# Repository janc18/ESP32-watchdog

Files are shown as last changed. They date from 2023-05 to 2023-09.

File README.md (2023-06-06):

# ESP32-watchdog 

This watch will be a multipurpose watch, that will have some kind of Espressif's MCU because it's cheap a come with good features like
Bluetooth and Wi-Fi.

I want to have the more compact design, with that said, the screen and battery define the size watch. 

Searching on Aliexpress I found the next options 

|ID|Technology type|Consumption (mAh) - Voltage (V)|Communication interface|Size|Price|Resolution|
|-|-|-|-|-|-|-|
|1|TFT-LCD|95mAh-5v|UART|47,5mm diameter x 27,0mm de height|371 MX|240px|
|2|Electronic paper screen Monochrome|0.15mAh|-|1.28in|574.29 MX 2 units| 128px|

**I decided to use the next LCD screen**

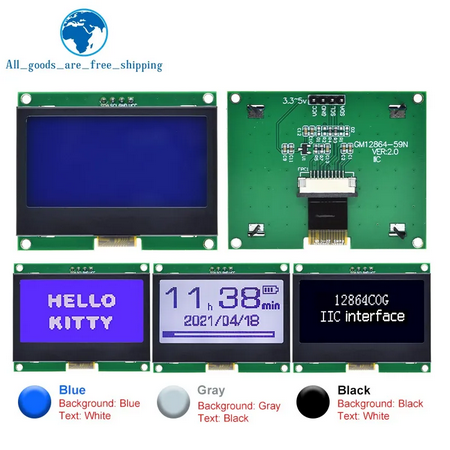
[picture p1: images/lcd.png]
lcd_screen


[Here is the purchase link](https://es.aliexpress.com/item/1005004617618178.html)

**Maybe in the next iteration I will choose for a smaller screen**

## Links
1. https://es.aliexpress.com/item/1005005295747021.html
2. https://es.aliexpress.com/item/1005004555311346.html

## Buttons 
For applications control it is needed to have some kind of inputs, like in common watches,with the hour configured through buttons.
One option is to have capacitive buttons or micro-buttons.

## Capacitive touch sensor
Following this document https://ww1.microchip.com/downloads/en/AppNotes/Capacitive-Touch-Sensor-Design-Guide-DS00002934-B.pdf
This type of sensor touch it seems the best option, it is called "slide sensor", at "Extend Interpolation" form.

## Programming port 
The programming port it will be a micro-usb with the CHG340

## ESP32-S3's power consumption 

|Mode|Power consumption|
|-|-|
|Recommended|500(mA)|
|deep sleep|7-8(uA)|
|light sleep|240(uA)|
|wifi|355mA|

In the case that I want to use Wi-Fi with another application running for three hours on a day and with powered on screen.

## Conceptual design

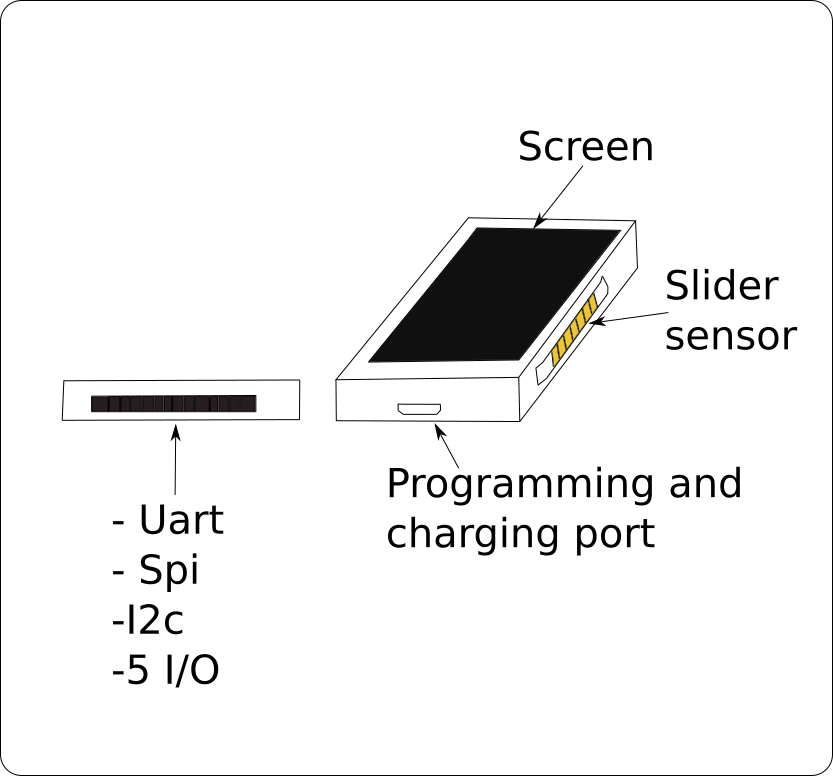
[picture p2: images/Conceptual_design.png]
design


## First PCB design

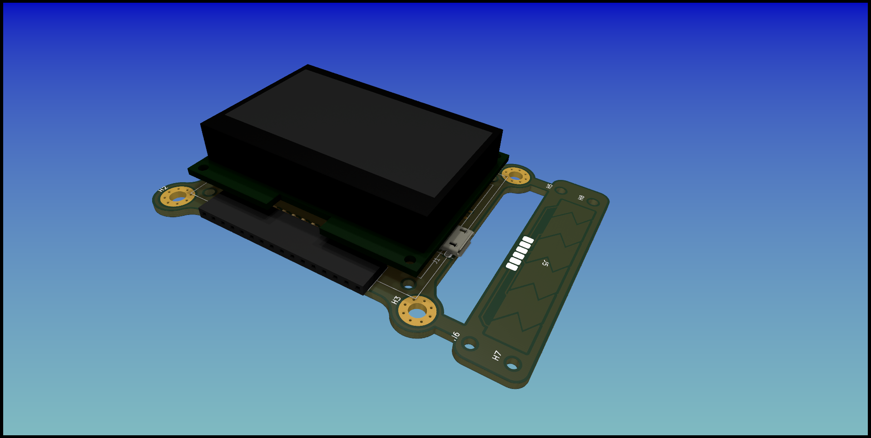
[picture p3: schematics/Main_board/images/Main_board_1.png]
design_pcb


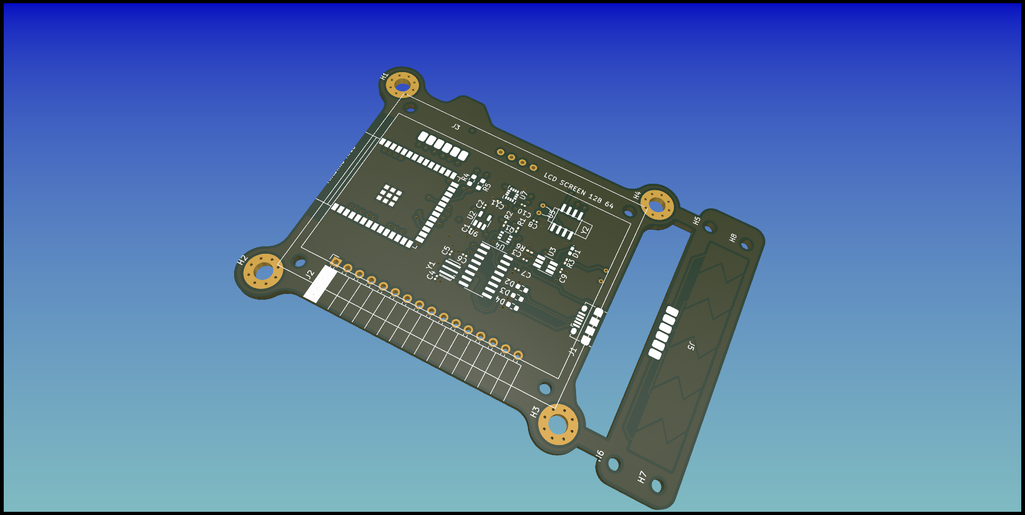
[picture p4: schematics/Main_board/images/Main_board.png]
design_pcb_1


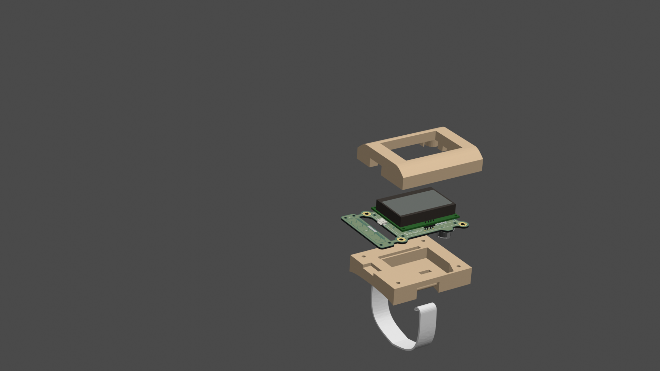
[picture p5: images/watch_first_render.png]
design_pcb_2


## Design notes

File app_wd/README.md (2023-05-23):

# app_wd

A new Flutter project.

## Getting Started

This project is a starting point for a Flutter application.

A few resources to get you started if this is your first Flutter project:

- [Lab: Write your first Flutter app](https://docs.flutter.dev/get-started/codelab)
- [Cookbook: Useful Flutter samples](https://docs.flutter.dev/cookbook)

For help getting started with Flutter development, view the
[online documentation](https://docs.flutter.dev/), which offers tutorials,
samples, guidance on mobile development, and a full API reference.

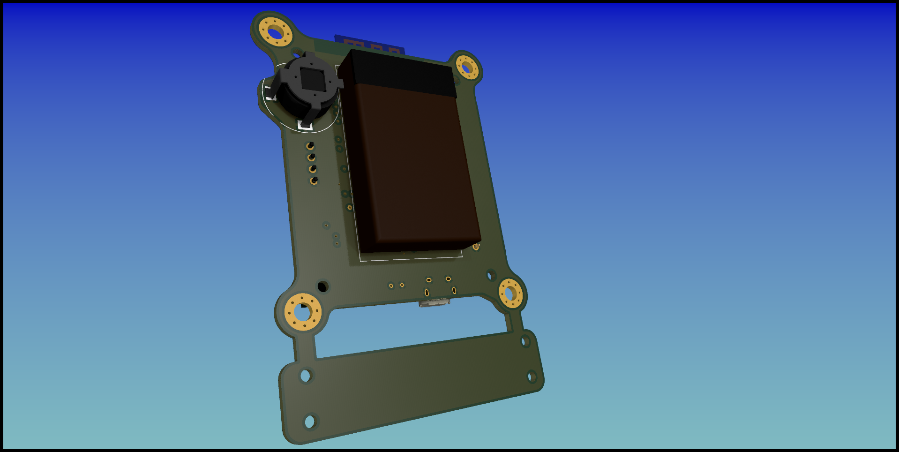
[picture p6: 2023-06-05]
schematics/Main_board/images/Main_board_2.png

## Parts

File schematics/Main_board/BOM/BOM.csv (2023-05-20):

Component | #LCSC part | Quantity | Package
ESD Protection Diode | C316054 | 3 | 0603
USB Micro-B | C132563 | 1 | SMD
Attitude Sensor/Gyroscope | C967633 | 1 | LGA-14
Real Time Clock | C7440 | 1 | SOIC-8
LDO 3v3 600mA | C51118 | 1 | SOT-25-5
Battery Management ICs | C202311 | 1 | SOT-23-6
Transceiver USB 2.0 | C14267 | 1 | SOP-16
i2c Pull-up Resistor | C25804 | 2 | 0603
100 nf | C14663 | 2 | 0603
1uf | C59302 | 2 | 0603

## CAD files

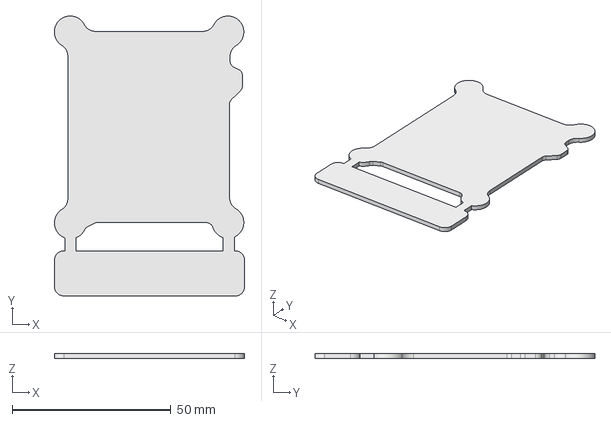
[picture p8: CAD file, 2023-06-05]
schematics/cut_layout/cuts_mainBoard.FCStd
59.9 x 88.1 x 1.60 mm

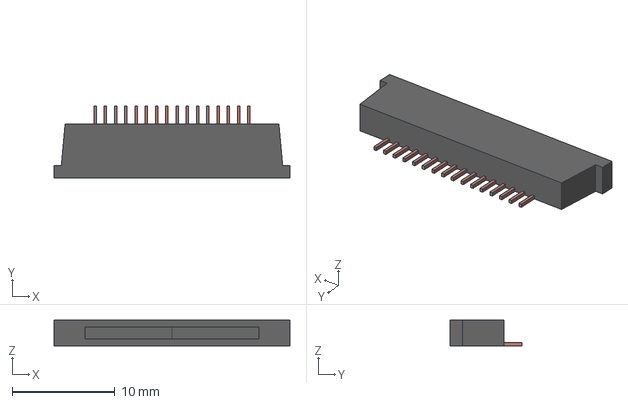
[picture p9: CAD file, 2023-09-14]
schematics/Main_board/Main_board/Step files/FCP-16p-1mm-Part.step
23.0 x 7.05 x 2.50 mm
Cuerpo

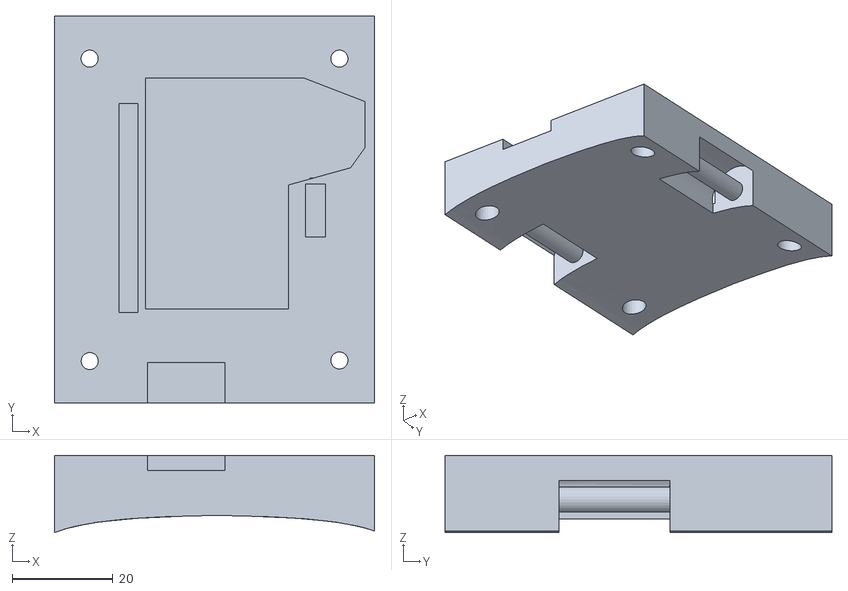
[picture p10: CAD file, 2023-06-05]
schematics/Main_board/Main_board/Step files/case-PartBody.stl
63.6 x 76.9 x 15.4

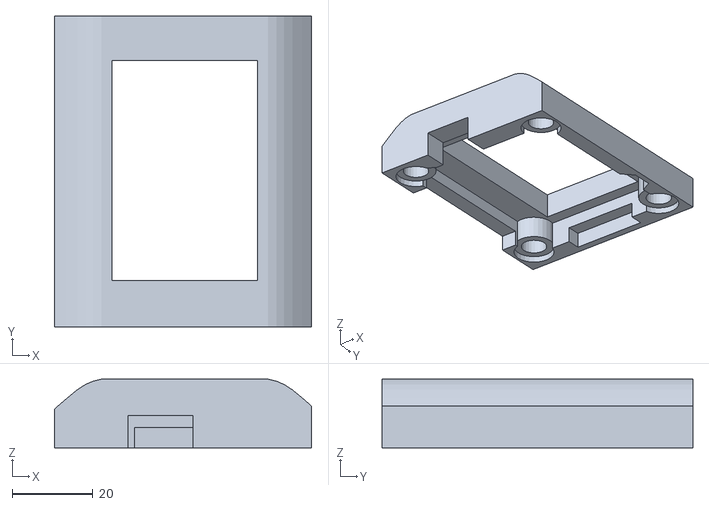
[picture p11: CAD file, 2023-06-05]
schematics/Main_board/Main_board/Step files/case-PartBody001.stl
63.6 x 76.9 x 17.0

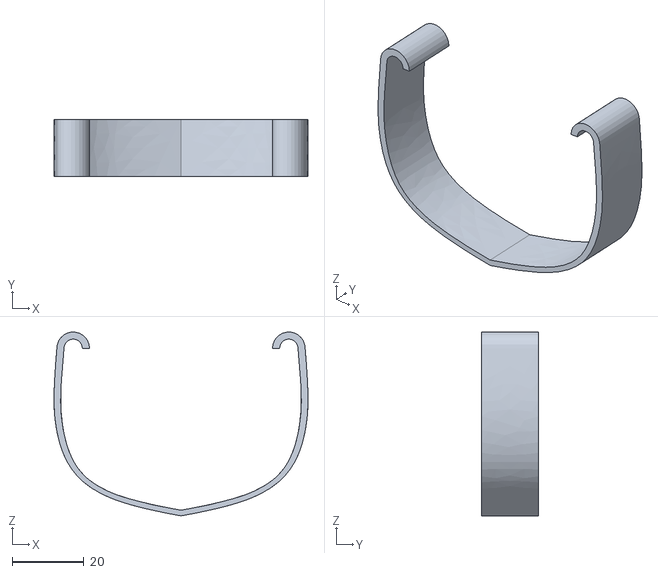
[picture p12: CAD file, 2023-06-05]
schematics/Main_board/Main_board/Step files/case-PartCorrea.stl
70.9 x 16.0 x 51.3

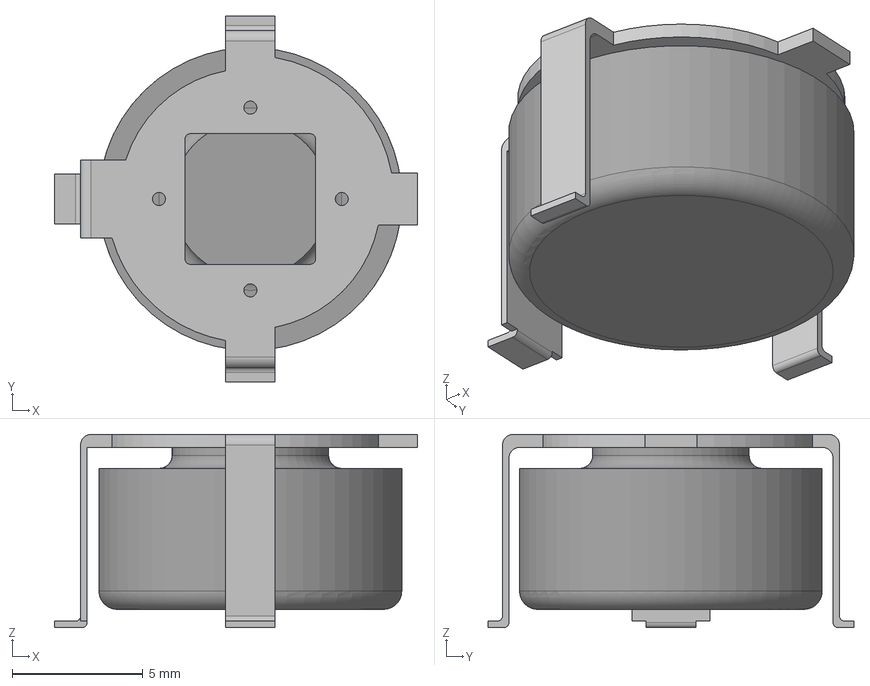
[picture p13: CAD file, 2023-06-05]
schematics/Main_board/Main_board/Step files/Battery_holder_LR44-Body.step
13.9 x 14.0 x 7.40 mm
Cell

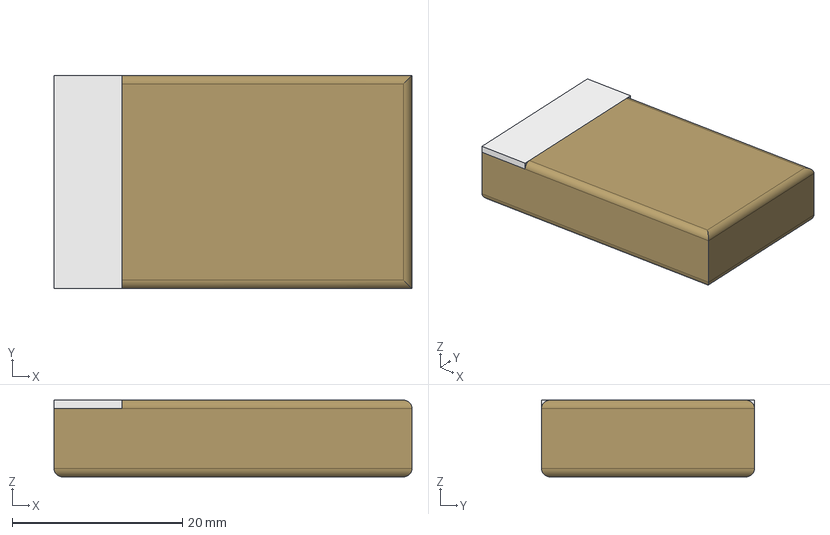
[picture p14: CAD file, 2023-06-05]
schematics/Main_board/Main_board/Step files/LiPo_battery-800mAh.FCStd
42.0 x 25.0 x 9.00 mm

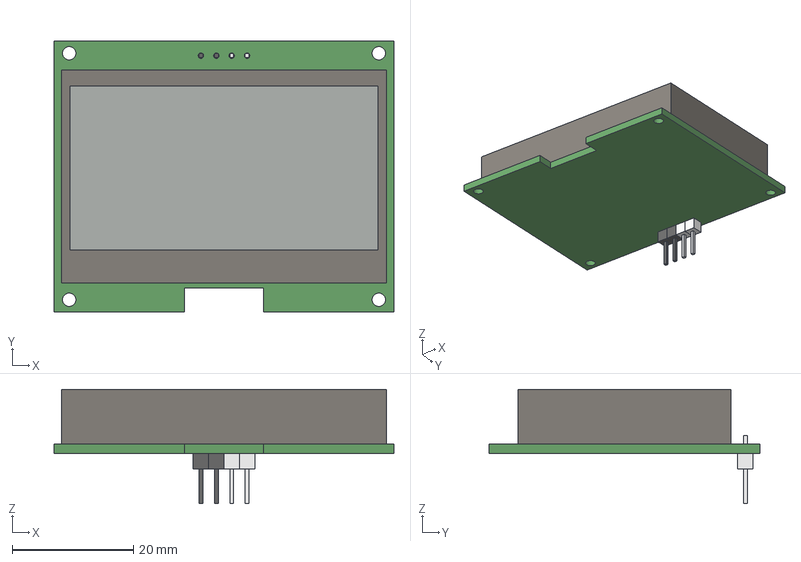
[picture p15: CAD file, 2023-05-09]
schematics/Main_board/Main_board/Step files/LCD screen.FCStd
56.0 x 44.6 x 18.8 mm
pin x 2
LCD
LCD_Housing
PCB

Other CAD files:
schematics/Main_board/Main_board/Step files/FCP-16p-1mm.FCStd
schematics/Main_board/Main_board/Step files/Battery_holder_LR44.FCStd
schematics/Main_board/Main_board/Step files/LiPo_battery-800mAh-Part.step
schematics/Main_board/Main_board/Step files/LCD screen-Part.step

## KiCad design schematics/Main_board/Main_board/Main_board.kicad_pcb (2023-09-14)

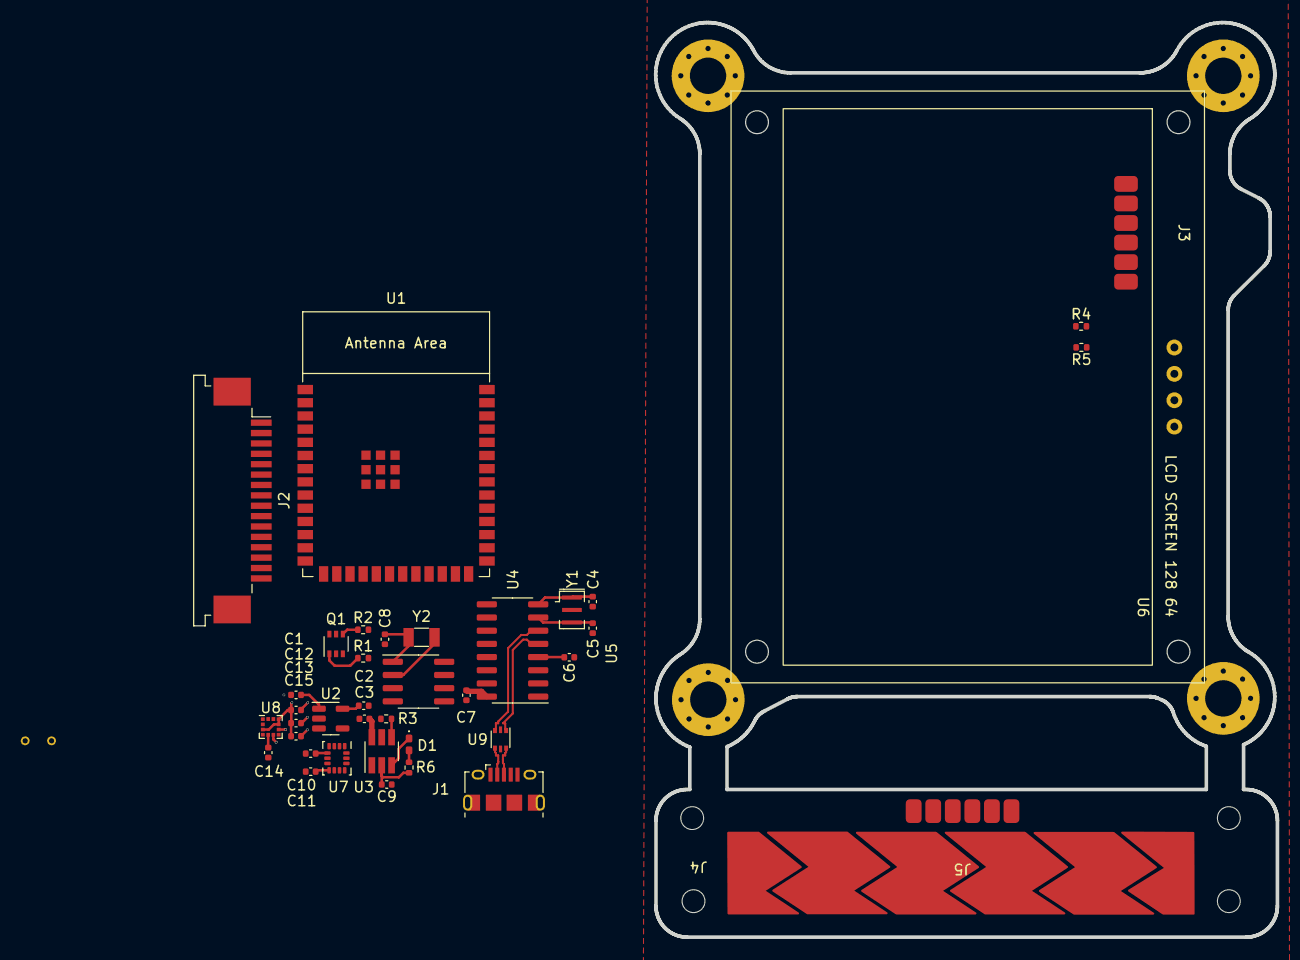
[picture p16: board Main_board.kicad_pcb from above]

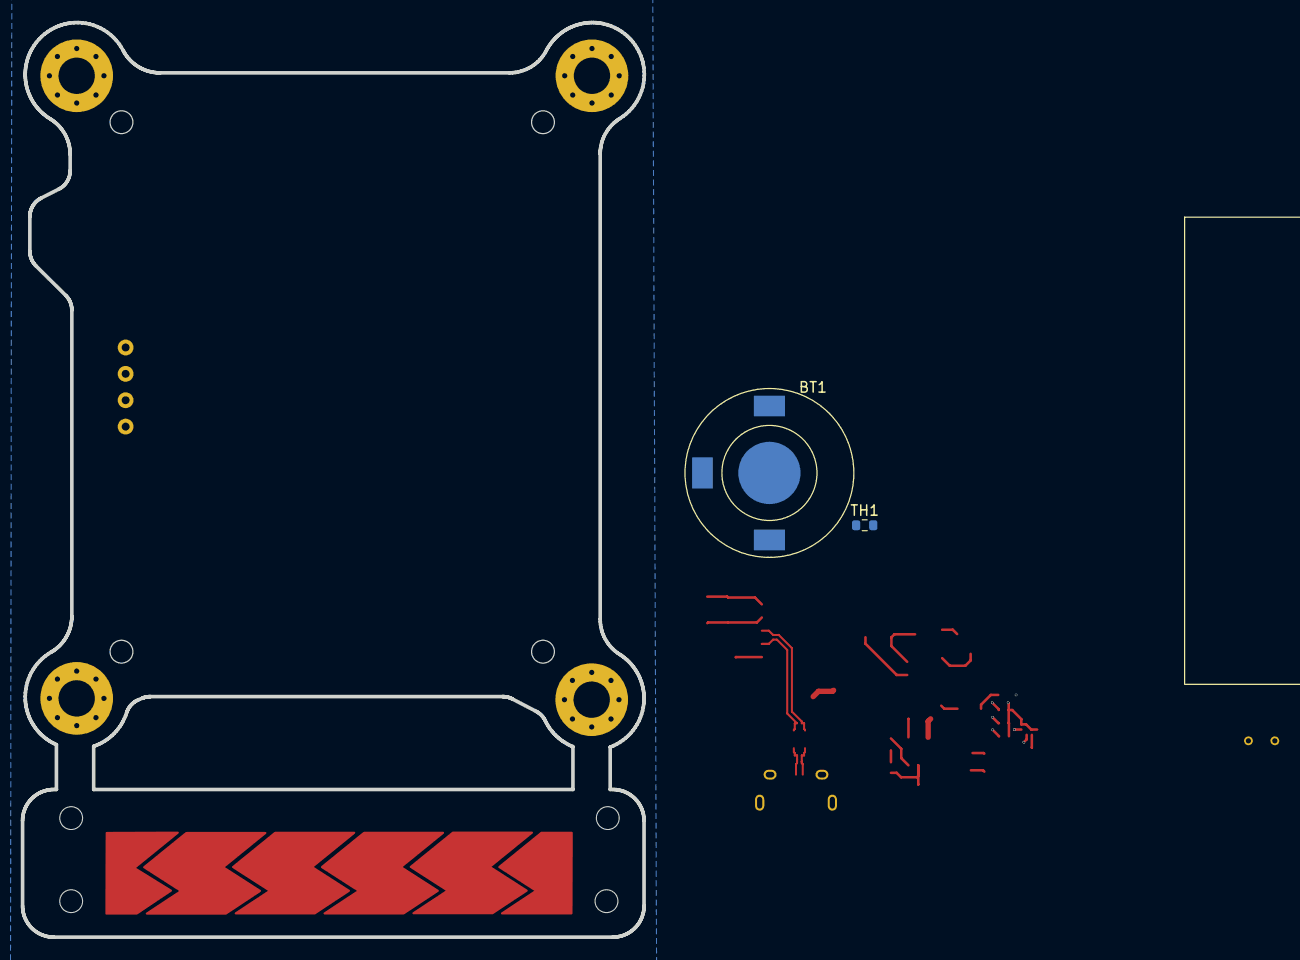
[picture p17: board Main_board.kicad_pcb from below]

Board: 4 copper layers, 59.9 x 88.1 mm, 50 parts (3 on the bottom side), 50 nets.

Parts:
BT1: 1v5 LR44; MY-LR44-02
BT2: 3v7 LIpo; lipo_battery_800mA
C1, C2, C3, C9: 1uf; C_0402_1005Metric
C4, C5: 33p; C_0402_1005Metric
C6, C7: 0.1u; C_0402_1005Metric
C8: 22p; C_0402_1005Metric
C10, C11, C12, C13: 100nf; C_0402_1005Metric
C14: 220nf; C_0402_1005Metric
C15: 10uf; C_0402_1005Metric
D1: LED; LED_0402_1005Metric_Pad0.77x0.64mm_HandSolder
H1, H2, H3, H4: MountingHole; MountingHole_3.5mm_Pad_Via
H5, H6, H7, H8: MountingHole; MountingHole_2.2mm_M2_DIN965
J1: USB_B_Micro; USB_Micro-B_Amphenol_10118194_Horizontal
J2: Conn_01x16_Female; TE_1-84953-6_1x16-1MP_P1.0mm_Horizontal
J3, J5: Conn_01x06_Female; slider_sensors_points_smd
J4: Conn_01x06_Female; slide_sensor_6p
Q1: UMH3N; SOT-363_SC-70-6
R1, R3: 1K; R_0402_1005Metric
R2: 10k; R_0402_1005Metric
R4, R5: 4k7; R_0402_1005Metric
R6: 1k5; R_0402_1005Metric
TH1: NCP18XH103F03RB; R_0603_1608Metric
U1: ESP32-S3-WROOM-1
U2: AP2112K-3.3; SOT-23-5
U3: bq21040; SOT-23-6_Handsoldering
U4: CH340G; SOIC-16_3.9x9.9mm_P1.27mm
U5: PCF8563T; SOIC-8_3.9x4.9mm_P1.27mm
U6: LCD; LCD_IIC_12864
U7: LSM6DS3; LGA-14_3x2.5mm_P0.5mm_LayoutBorder3x4y
U8: LIS2MDL; LGA-12_2x2mm_P0.5mm
U9: USBLC6-2P6; SOT-666
Y1: Crystal_GND2_Small; Resonator_SMD_Murata_CSTxExxV-3Pin_3.0x1.1mm
Y2: 32.768kHz; Crystal_SMD_3215-2Pin_3.2x1.5mm

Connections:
+3V3: C2.1, C10.1, C11.2, C12.1, C13.1, C15.1, J2.1, J2.2, Q1.3 (C2), Q1.6 (C1), R4.2, R5.1, U2.5 (VOUT), U6.4 (Vcc), U7.5 (VDDIO), U7.8 (VDD), U7.12 (CS), U8.3 (~CS), U8.9 (Vdd), U8.10 (Vdd_IO)
+5V: C3.2, C7.1, U3.6 (VIN), U4.16 (VCC), U9.2 (GND)
+BATT: BT2.1 (+), C1.1, C9.2, R6.2, U2.1 (VIN), U2.3 (EN), U3.2 (VOUT)
/BOOT0: R1.2, U1.27 (GPIO0/BOOT)
/Connectors/D_ESD+: J1.3 (D+), U9.6 (I/O1)
/Connectors/D_ESD-: J1.2 (D-), U9.4 (I/O2)
/D+: U4.5 (UD+), U9.1 (I/O1)
/D-: U4.6 (UD-), U9.3 (I/O2)
/DTR: Q1.5 (B2), U4.13 (~DTR)
/EN: R2.2, U1.3 (EN)
/I/O_1: J2.3, U1.39 (GPIO1/TOUCH1/ADC1_CH0)
/I/O_2: J2.4, U1.38 (GPIO2/TOUCH2/ADC1_CH1)
/I/O_3: J2.5, U1.15 (GPIO3/TOUCH3/ADC1_CH2)
/I/O_4: J2.6, U1.4 (GPIO4/TOUCH4/ADC1_CH3)
/I/O_5: J2.7, U1.5 (GPIO5/TOUCH5/ADC1_CH4)
/MISO: J2.13, U1.21 (GPIO13/TOUCH13/ADC2_CH2/FSPIQ/FSPIIO7/S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)
/MOSI: J2.12, U1.19 (GPIO11/TOUCH11/ADC2_CH0/FSPID/FSPIIO5/S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)
/RTS: Q1.2 (B1), U4.14 (~RTS)
/SCL_1: J2.11, R4.1, U1.23 (GPIO21), U5.5 (SDA), U6.1 (SDA), U7.14 (SDA), U8.4 (SDA/SDI/SDO)
/SDA_1: J2.10, R5.2, U1.26 (GPIO45), U5.6 (SCL), U6.2 (SCL), U7.13 (SCL), U8.1 (SCL/SPC)
/SPI_CLK: J2.14, U1.20 (GPIO12/TOUCH12/ADC2_CH1/FSPICLK/FSPIIO6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)
/TOUCH_1: J3.1, U1.6 (GPIO6/TOUCH6/ADC1_CH5)
/TOUCH_2: J3.2, U1.7 (GPIO7/TOUCH7/ADC1_CH6)
/TOUCH_3: J3.3, U1.12 (GPIO8/TOUCH8/ADC1_CH7/SUBSPICS1)
/TOUCH_4: J3.4, U1.17 (GPIO9/TOUCH9/ADC1_CH8/FSPIHD/SUBSPIHD)
/TOUCH_5: J3.5, U1.18 (GPIO10/TOUCH10/ADC1_CH9/FSPICS0/FSPIIO4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)
/TOUCH_6: J3.6, U1.22 (GPIO14/TOUCH14/ADC2_CH3/FSPIWP/FSPIDQS/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)
/UART_RX0_PGR: J2.9, U1.37 (U0TXD/GPIO43/CLK_OUT1), U4.3 (RXD)
/UART_TX0_PGR: J2.8, U1.36 (U0RXD/GPIO44/CLK_OUT2), U4.2 (TXD)
GNDREF: BT1.2 (-), BT2.2 (-), C1.2, C2.2, C3.1, C4.2, C5.2, C6.1, C7.2, C8.2, C9.1, C10.2, C11.1, C12.2, C13.2, C14.2, C15.2, J1.4 (ID), J1.5 (GND), J1.6 (Shield), J2.15, J2.16, R3.2, TH1.2, U1.1 (GND), U1.40 (GND), U1.41 (GND), U2.2 (GND), U3.5 (GND), U4.1 (GND), U5.4 (VSS), U6.3 (GND), U7.1 (SDO/SA0), U7.2 (SDX), U7.3 (SCX), U7.6 (GND), U7.7 (GND), U8.6 (GND), U8.8 (GND), Y1.2
unnamed: BT1.1 (+), U5.8 (VDD)
unnamed: D1.2 (A), R6.1
unnamed: D1.1 (K), U3.3 (CHR)
unnamed: J4.1, J5.1
unnamed: J4.2, J5.2
unnamed: J4.3, J5.3
unnamed: J4.4, J5.4
unnamed: J4.5, J5.5
unnamed: J4.6, J5.6
unnamed: Q1.1 (E1), R1.1
unnamed: Q1.4 (E2), R2.1
unnamed: R3.1, U3.4 (ISET)
unnamed: TH1.1, U3.1 (TS)
unnamed: C6.2, U4.4 (V3)
unnamed: C5.1, U4.7 (XI), Y1.3
unnamed: C4.1, U4.8 (XO), Y1.1
unnamed: C8.1, U5.1 (OSCI), Y2.1
unnamed: U5.2 (OSCO), Y2.2
unnamed: C14.1, U8.5 (C1)
VBUS: J1.1 (VBUS), U9.5 (VBUS)

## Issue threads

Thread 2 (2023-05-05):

Preliminary PCB Design for Slider Sensor and Main PCB

janc18, 2023-05-05:
To have an idea of the size for the PCBs is required to make a preliminary design.

It will be needed 2 PCBs for:
- Slider sensor
- Main PCB

The main PCB will contain the next components
|Female headers pin|Description|
|-|-|
|5 IO||
|2 Vdd||
|2 Vss||
|2 |UART(Tx,Rx)|
| 2| I2c(SDA,SCL)|
|3 |SPI(MOSI,MISO,CLK)|

**Total:16 Female headers**

|Component|Description|LCSC part|
|-|-|-|
ESP32-S3             	|Main MCU  |	C2913198|
CH340G|UART-Bridge|C14267
RTC|Real Time Clock|C7440|
Battery socket|Supply for RTC|	C964716|
USB Port             	|HID USB Port                         |C428495|
LDO's MCU and Screen                  |Low dropout Regulator(3v3)           |C51118|
|Battery|LiPo Battery 3.7v 800mAh|
Battery Charger             |Circuit to charge battery            |C202311|
Female Headers| UART,SPI,I2c sockets|C2897398|

Related ch340 Esp downloading programming:https://pcbartists.com/design/embedded/esp32-ch340-programmer-schematic/
Related battery information:https://ecocell.com.au/product/lipo-850-902540/
Approximation LCD consumption: 70mA with backlight
Recommend MCU mAh consumption: 500mA
LDO recommended for LCD and MCU:3.3v 600mA

janc18, 2023-05-09:
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

Closed 2023-05-09.

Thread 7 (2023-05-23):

Way of charge?

janc18, 2023-05-23:
I have some doubts about the operation when the battery is charging.
If the battery is being charged, the clock will take the 4.2v from the battery and regulate it to 3.3v.
Or the 5v input from the charging port will charge the battery, plus if the watch is in use it will be powered from the charging port.

janc18, 2023-06-05:
Because I selected the **BQ21040** Lipo battery IC.
This IC, power down when the **IN** terminal voltage is less than UVLO and the all the terminals are high impedance

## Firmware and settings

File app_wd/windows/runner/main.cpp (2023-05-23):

#include <flutter/dart_project.h>
#include <flutter/flutter_view_controller.h>
#include <windows.h>

#include "flutter_window.h"
#include "utils.h"

int APIENTRY wWinMain(_In_ HINSTANCE instance, _In_opt_ HINSTANCE prev,
                      _In_ wchar_t *command_line, _In_ int show_command) {
  // Attach to console when present (e.g., 'flutter run') or create a
  // new console when running with a debugger.
  if (!::AttachConsole(ATTACH_PARENT_PROCESS) && ::IsDebuggerPresent()) {
    CreateAndAttachConsole();
  }

  // Initialize COM, so that it is available for use in the library and/or
  // plugins.
  ::CoInitializeEx(nullptr, COINIT_APARTMENTTHREADED);

  flutter::DartProject project(L"data");

  std::vector<std::string> command_line_arguments =
      GetCommandLineArguments();

  project.set_dart_entrypoint_arguments(std::move(command_line_arguments));

  FlutterWindow window(project);
  Win32Window::Point origin(10, 10);
  Win32Window::Size size(1280, 720);
  if (!window.Create(L"app_wd", origin, size)) {
    return EXIT_FAILURE;
  }
  window.SetQuitOnClose(true);

  ::MSG msg;
  while (::GetMessage(&msg, nullptr, 0, 0)) {
    ::TranslateMessage(&msg);
    ::DispatchMessage(&msg);
  }

  ::CoUninitialize();
  return EXIT_SUCCESS;
}

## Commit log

2023-04-03 remove: Circuit block diagram
2023-05-05 Add: Kicad schematics files
    [Main_board.kicad_pcb, Main_board.kicad_sch]
2023-05-05 Add: Slider_sensor_board Kicad schematics files
    [Slider_sensor_board.kicad_pcb, Slider_sensor_board.kicad_sch]
2023-05-05 Update:added new rule of kicad backups
2023-05-09 Update: Added symbols and footprints
    [Main_board.kicad_pcb, Main_board.kicad_sch]
2023-05-09 Update: Added LCD symbol
    [Main_board.kicad_pcb, Main_board.kicad_sch]
2023-05-09 Add: Creation of 3d file (FCStd an STEP)
    [LCD screen-Part.step, LCD screen.FCStd]
2023-05-09 Add: Creation of schematic and footprint
2023-05-10 Add: Battery holder 3D design STEP and FCStd
    [Battery_holder_LR44-Body.step, Battery_holder_LR44.FCStd]
2023-05-10 Add: LiPo battery 3D design STEP and FCStd
    [LiPo_battery-800mAh-Part.step, LiPo_battery-800mAh.FCStd]
2023-05-10 Add: Battery holder footprint
2023-05-10 Update: added new schematics components
    [Main_board.kicad_pcb, Main_board.kicad_sch]
2023-05-15 Add: footprint for slide sensor
2023-05-15 Update: add components to schematics
    [Main_board.kicad_pcb, Main_board.kicad_sch]
2023-05-20 Add: BOM file
    [BOM.csv]
2023-05-20 Update: added datasheet to KiCad component
    [Main_board.kicad_pcb, Main_board.kicad_sch]
2023-05-23 Update: added a new field for kicad components for the #lcsc part
    [Main_board.kicad_sch]
2023-05-23 delete: slider sensor board because it will be include in the main board
    [Slider_sensor_board.kicad_pcb, Slider_sensor_board.kicad_sch]
2023-06-05 Add: Label sticker with all the connections(i/o,uart,spi and i2c)
2023-06-05 Update: First pcb revision complete
    [Main_board.kicad_pcb, Main_board.kicad_sch]
2023-06-05 Add: designs for 3d parts and footprints
2023-06-05 Add: layout to do the cuts in kicad
    [cuts_mainBoard.FCStd]
2023-06-05 Update: change colors
    [Battery_holder_LR44-Body.step, Battery_holder_LR44.FCStd, LiPo_battery-800mAh-Part.step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]
2023-06-05 Add: FreeCad case file and stl files
    [case-PartBody.stl, case-PartBody001.stl, case-PartCorrea.stl]
2023-06-05 Update: added new rule for backups kicad's files
2023-09-10 update: to kicad version 7, and arrange all the components on their respective hierarchy page
    [Main_board.kicad_pcb, Main_board.kicad_sch, Sensors.kicad_sch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]
2023-09-10 fix: 3d step file paths
    [Battery_holder_LR44-Body.step, Battery_holder_LR44.FCStd, LCD screen-Part.step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]
2023-09-14 update: All the resistors and capacitors footprints changed from 0603 to 0402
    [FCP-16p-1mm-Part.step, FCP-16p-1mm.FCStd, Main_board.kicad_pcb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]
